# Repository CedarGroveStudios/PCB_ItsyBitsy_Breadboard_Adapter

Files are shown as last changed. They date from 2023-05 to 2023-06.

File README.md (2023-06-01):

### _A stacking breadboard adapter for the ItsyBitsy M4 Express_

# ItsyBitsy Breadboard Adapter

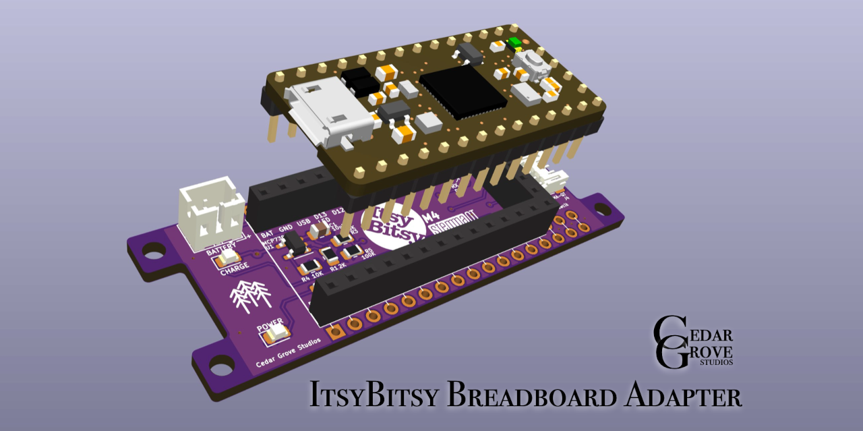
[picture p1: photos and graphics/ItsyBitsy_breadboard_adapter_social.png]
Image of Module


## Overview
The ItsyBitsy Breadboard Adapter is an Adafruit ItsyBitsy M4 Express-compatible piggyback module that converts the 3-sided pinout of the ItsyBitsy to dual in-line for use on typical solderless breadboards and soldered protoboards. The adapter was also designed with extra solderable pin connections and mounting ears for permanent installation.

Included is a STEMMA-QT connector that can be optionally configured via solder jumpers to connect to the ItsyBitsy's UART (RX/TX) or I2C (SCL/SDA) signals. A 2-pin JST LiPo battery connection is on-board that supports charging (100mA charge rate), compatible with Adafruit's standard battery connector polarity. A solder jumper is also provided to optionally connect the battery monitor voltage divider to pin A6.

ItsyBitsy Breadboard Adapter [Schematic](https://github.com/CedarGroveStudios/PCB_ItsyBitsy_Breadboard_Adapter/blob/main/PCB/ItsyBitsy%20breadboard.pdf)

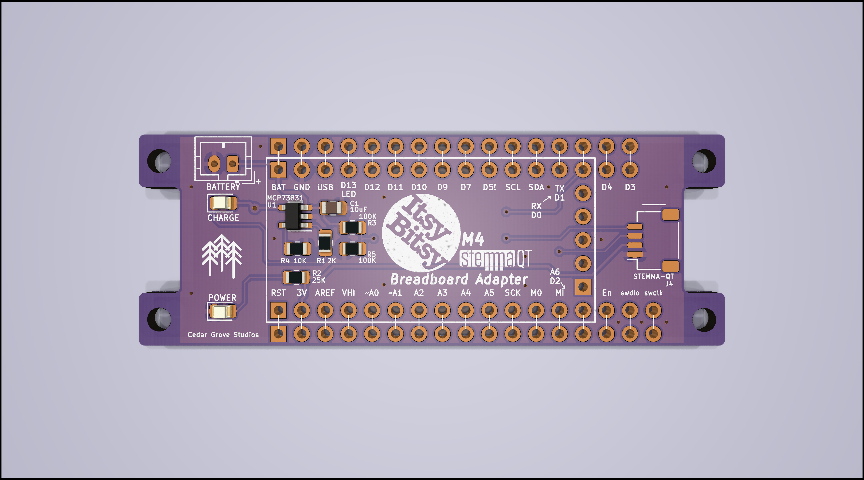
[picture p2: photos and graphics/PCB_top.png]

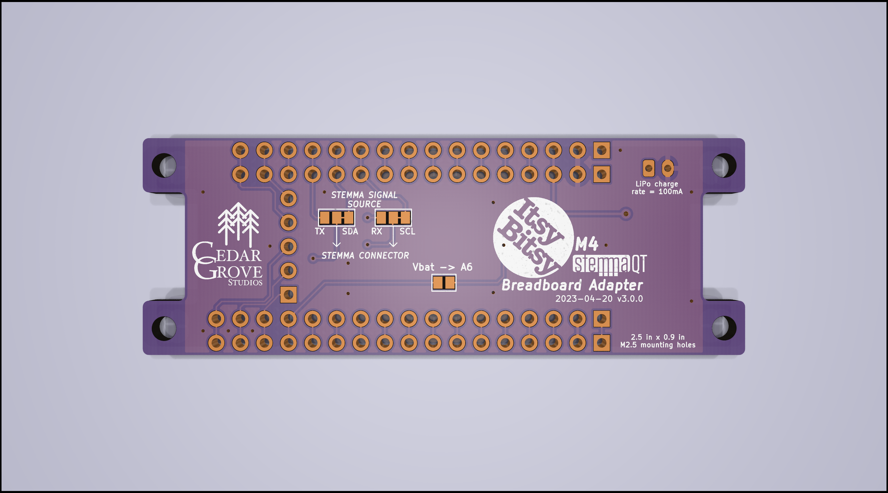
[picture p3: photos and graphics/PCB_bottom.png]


OSH Park shared project:

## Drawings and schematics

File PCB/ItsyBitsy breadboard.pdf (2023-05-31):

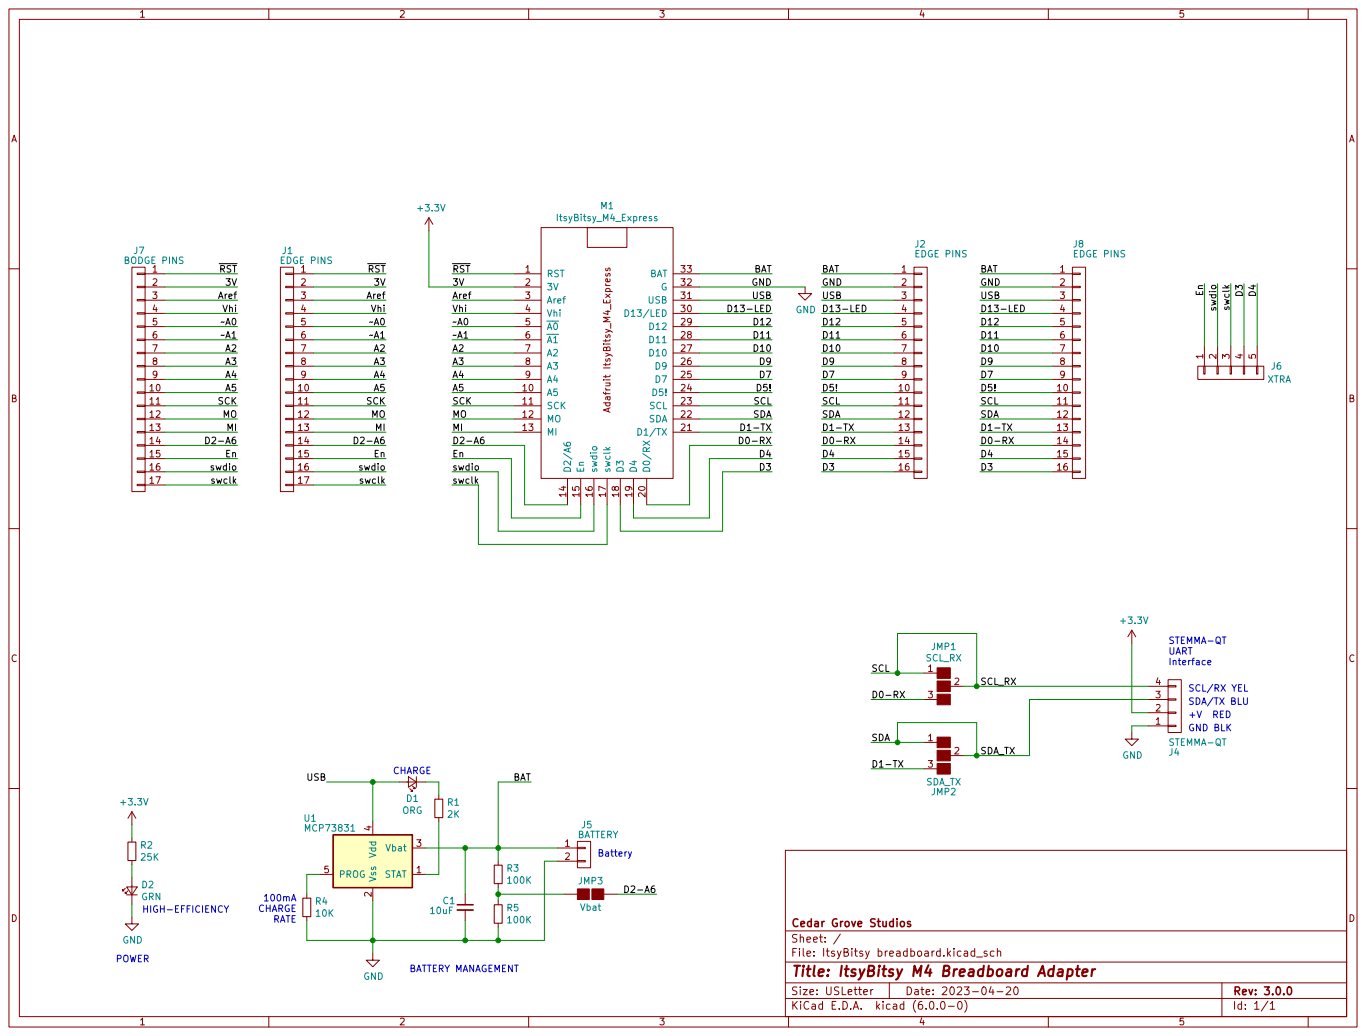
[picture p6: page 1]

File: ItsyBitsy breadboard.kicad_sch Sheet: / Cedar Grove Studios

Id: 1/1 Title: ItsyBitsy M4 Breadboard Adapter

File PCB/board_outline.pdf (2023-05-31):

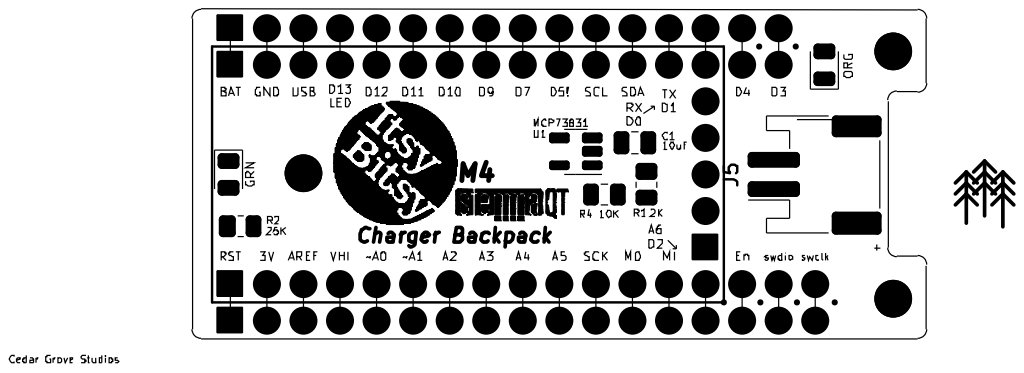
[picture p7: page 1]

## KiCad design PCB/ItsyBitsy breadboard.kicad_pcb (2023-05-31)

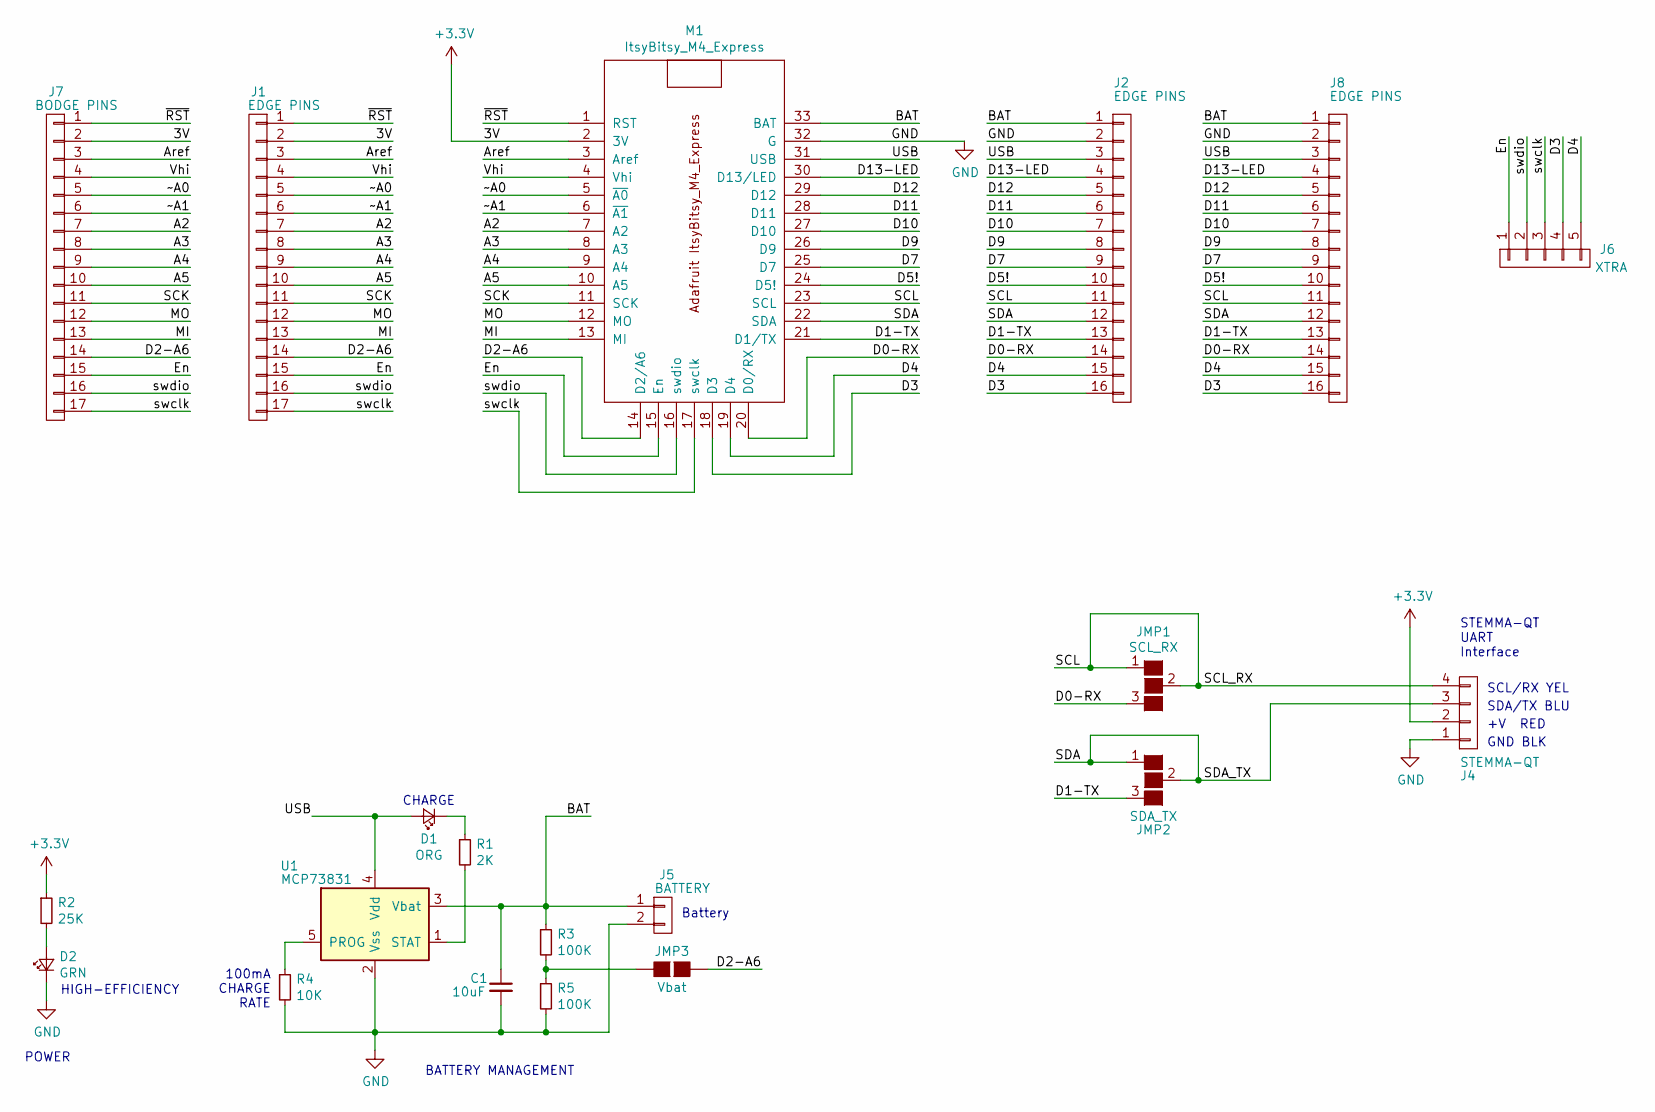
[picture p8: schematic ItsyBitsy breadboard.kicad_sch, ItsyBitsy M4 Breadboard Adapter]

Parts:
C1: 10uF; C_0805_2012Metric
D1: ORG; LED_0805_2012Metric
D2: GRN; LED_0805_2012Metric
J1: EDGE PINS; Pin_Header_Straight_1x17_Pitch2.54mm_no_silk
J2, J8: EDGE PINS; Pin_Header_Straight_1x16_Pitch2.54mm_no_silk
J4: STEMMA-QT; JST_SH_SM04B-SRSS-TB_1x04-1MP_P1.00mm_Horizontal
J5: BATTERY; JST_PH_B2B-PH-K_1x02_P2.00mm_Vertical
J6: XTRA; Pin_Header_Straight_1x05_Pitch2.54mm_no_silk
J7: BODGE PINS; Pin_Header_Straight_1x17_Pitch2.54mm_no_silk
JMP1: SCL_RX; GS3
JMP2: SDA_TX; GS3
JMP3: Vbat; GS2
M1: ItsyBitsy_M4_Express
R1: 2K; R_0805_2012Metric
R2: 25K; R_0805_2012Metric
R3, R5: 100K; R_0805_2012Metric
R4: 10K; R_0805_2012Metric
U1: MCP73831; SOT-23-5

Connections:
+3V3: J1.2, J4.2, J7.2, M1.2 (3V), R2.1
/A2: J1.7, J7.7, M1.7 (A2)
/A3: J1.8, J7.8, M1.8 (A3)
/A4: J1.9, J7.9, M1.9 (A4)
/A5: J1.10, J7.10, M1.10 (A5)
/Aref: J1.3, J7.3, M1.3 (Aref)
/BAT: C1.1, J2.1, J5.1, J8.1, M1.33 (BAT), R3.1, U1.3 (Vbat)
/D0-RX: J2.14, J8.14, JMP1.3 (G3), M1.20 (D0/RX)
/D1-TX: J2.13, J8.13, JMP2.3 (G3), M1.21 (D1/TX)
/D2-A6: J1.14, J7.14, JMP3.1 (G1), M1.14 (D2/A6)
/D3: J2.16, J6.4, J8.16, M1.18 (D3)
/D4: J2.15, J6.5, J8.15, M1.19 (D4)
/D5!: J2.10, J8.10, M1.24 (D5!)
/D7: J2.9, J8.9, M1.25 (D7)
/D9: J2.8, J8.8, M1.26 (D9)
/D10: J2.7, J8.7, M1.27 (D10)
/D11: J2.6, J8.6, M1.28 (D11)
/D12: J2.5, J8.5, M1.29 (D12)
/D13-LED: J2.4, J8.4, M1.30 (D13/LED)
/En: J1.15, J6.1, J7.15, M1.15 (En)
/MI: J1.13, J7.13, M1.13 (MI)
/MO: J1.12, J7.12, M1.12 (MO)
/SCK: J1.11, J7.11, M1.11 (SCK)
/SCL: J2.11, J4.4, J8.11, JMP1.1 (G1), JMP1.2 (G2), M1.23 (SCL)
/SDA: J2.12, J4.3, J8.12, JMP2.1 (G1), JMP2.2 (G2), M1.22 (SDA)
/USB: D1.2 (A), J2.3, J8.3, M1.31 (USB), U1.4 (Vdd)
/Vhi: J1.4, J7.4, M1.4 (Vhi)
/swclk: J1.17, J6.3, J7.17, M1.17 (swclk)
/swdio: J1.16, J6.2, J7.16, M1.16 (swdio)
/~A0: J1.5, J7.5, M1.5 (~A0)
/~A1: J1.6, J7.6, M1.6 (~A1)
/~RST: J1.1, J7.1, M1.1 (RST)
GND: C1.2, D2.1 (K), J2.2, J4.1, J5.2, J8.2, M1.32 (G), R4.2, R5.2, U1.2 (Vss)
unnamed: D1.1 (K), R1.1
unnamed: D2.2 (A), R2.2
unnamed: JMP3.2 (G2), R3.2, R5.1
unnamed: R1.2, U1.1 (STAT)
unnamed: R4.1, U1.5 (PROG)

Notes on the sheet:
BATTERY MANAGEMENT
GND BLK
SDA/TX BLU
CHARGE
SCL/RX YEL
Battery
HIGH-EFFICIENCY
STEMMA-QT UART Interface
+V RED
POWER
100mA CHARGE RATE

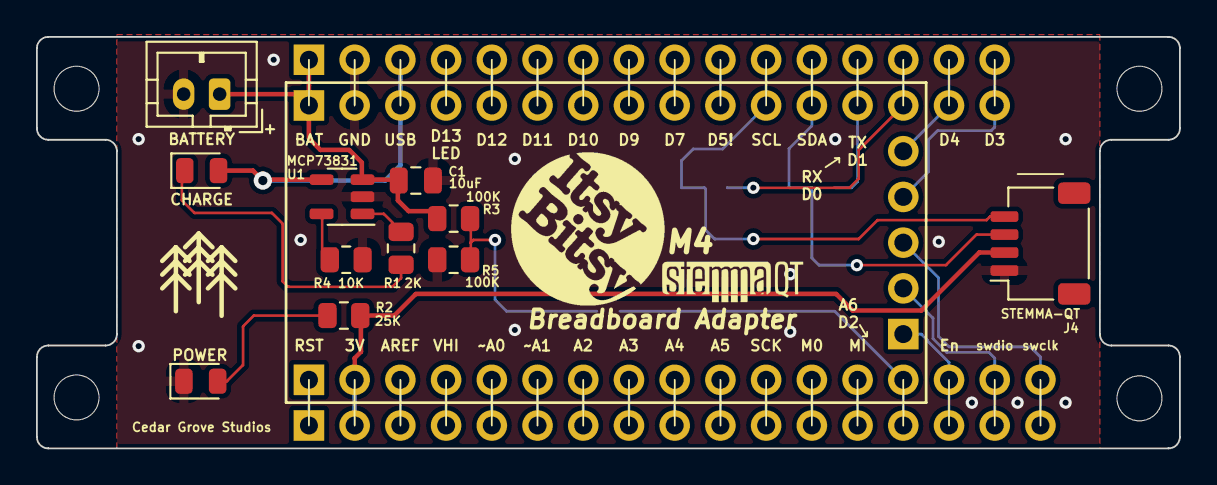
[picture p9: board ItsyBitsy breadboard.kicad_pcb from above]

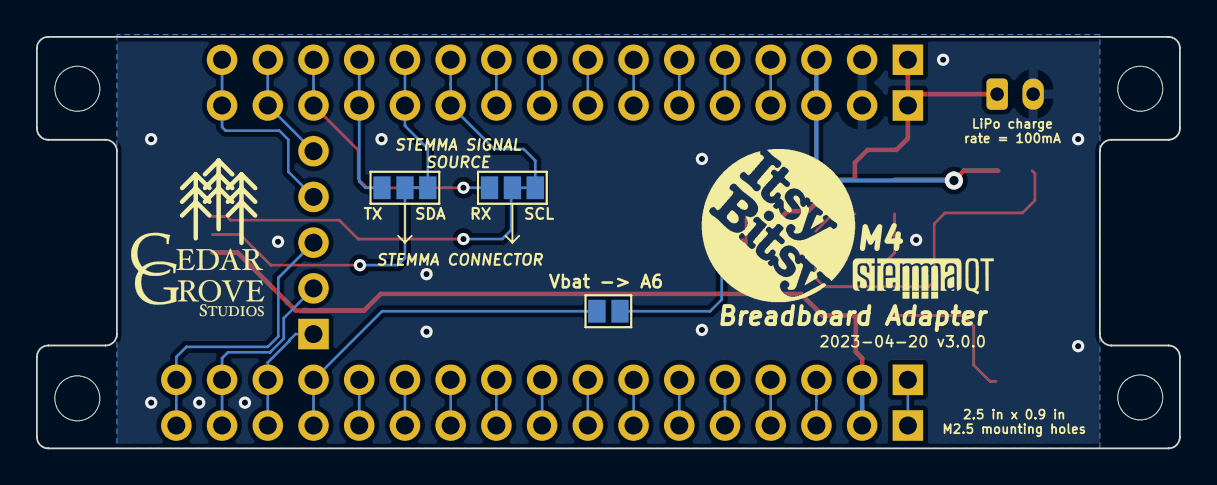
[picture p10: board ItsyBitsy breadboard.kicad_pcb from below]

Board: 2 copper layers, 63.5 x 22.9 mm, 21 parts (4 on the bottom side), 38 nets.

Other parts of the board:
logo: ItsyBitsy_logo
logo#2: ItsyBitsy_logo

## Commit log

2023-05-31 initial repo load
    [ItsyBitsy breadboard-B_Cu.gbl, ItsyBitsy breadboard-B_Mask.gbs, ItsyBitsy breadboard-B_Paste.gbp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]
2023-06-02 update kicad backups
